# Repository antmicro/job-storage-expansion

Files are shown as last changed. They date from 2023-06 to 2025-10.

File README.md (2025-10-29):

# Jetson Orin Baseboard Storage Expansion Board

Copyright (c) 2023-2025 [Antmicro](https://www.antmicro.com)

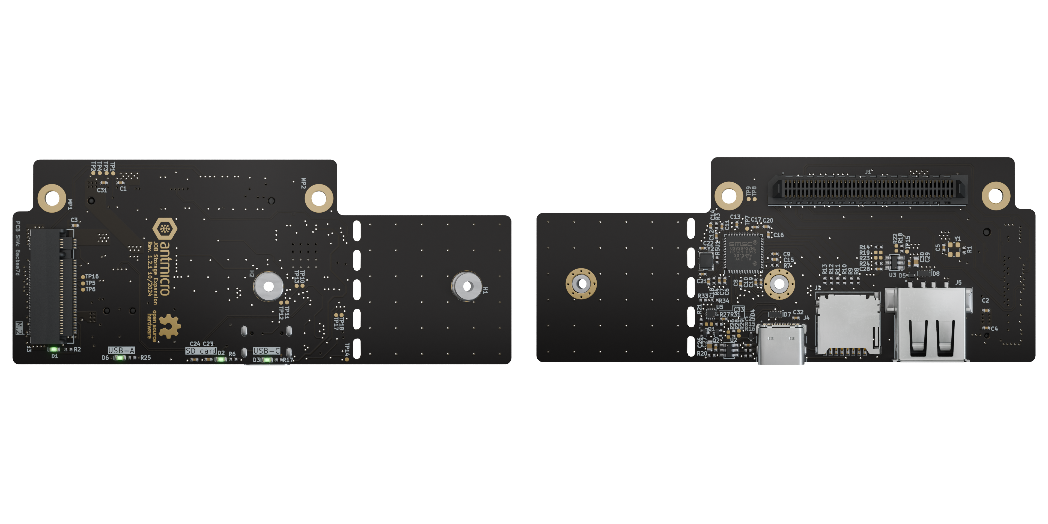
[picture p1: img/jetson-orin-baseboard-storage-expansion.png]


## Overview

This project contains open hardware design files for an expansion board compatible with Antmicro's [Jetson Orin Baseboard](https://github.com/antmicro/jetson-orin-baseboard).
The expansion board includes a MicroSD card slot and an M.2 (key-M) slot intended for connecting additional storage solutions to the Jetson Orin Baseboard.
It also includes an additional USB-C and USB type A connectors.
The M.2 slot supports 2280 and 2242 M.2 NVMe discs. 
The design files were prepared in KiCad 9.x.

## Key features

* Jetson Orin Baseboard expansion connector
* Support for 2280 and 2242 disc sizes
* M.2 key M
* MicroSD card reader with USB 2.0 interface
* USB-C and USB type A

## Project structure 

The main directory contains KiCad PCB project files, LICENSE, and README.
The remaining files are stored in the following directories: 
 
* `img` - contains graphics for this README

## Licensing

This project is published under the [Apache-2.0](LICENSE) license.

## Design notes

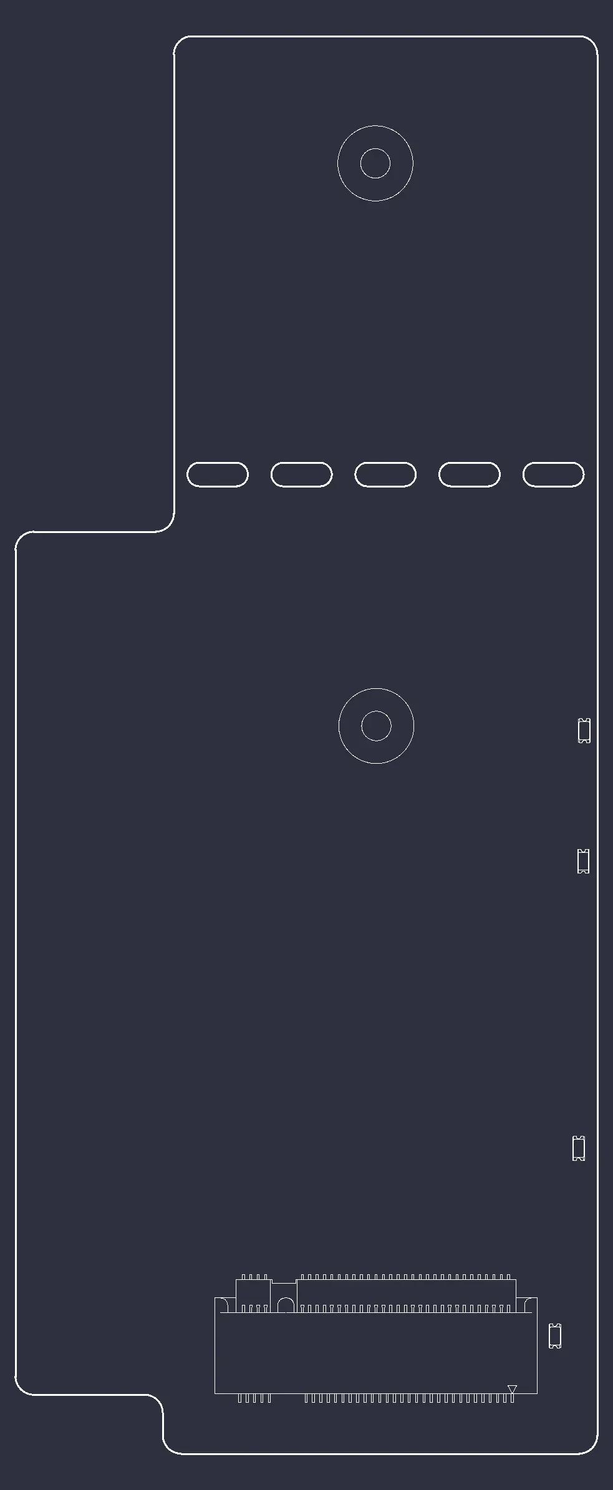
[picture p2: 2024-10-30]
assets/wireframe/wireframe_descriptions_top.webp

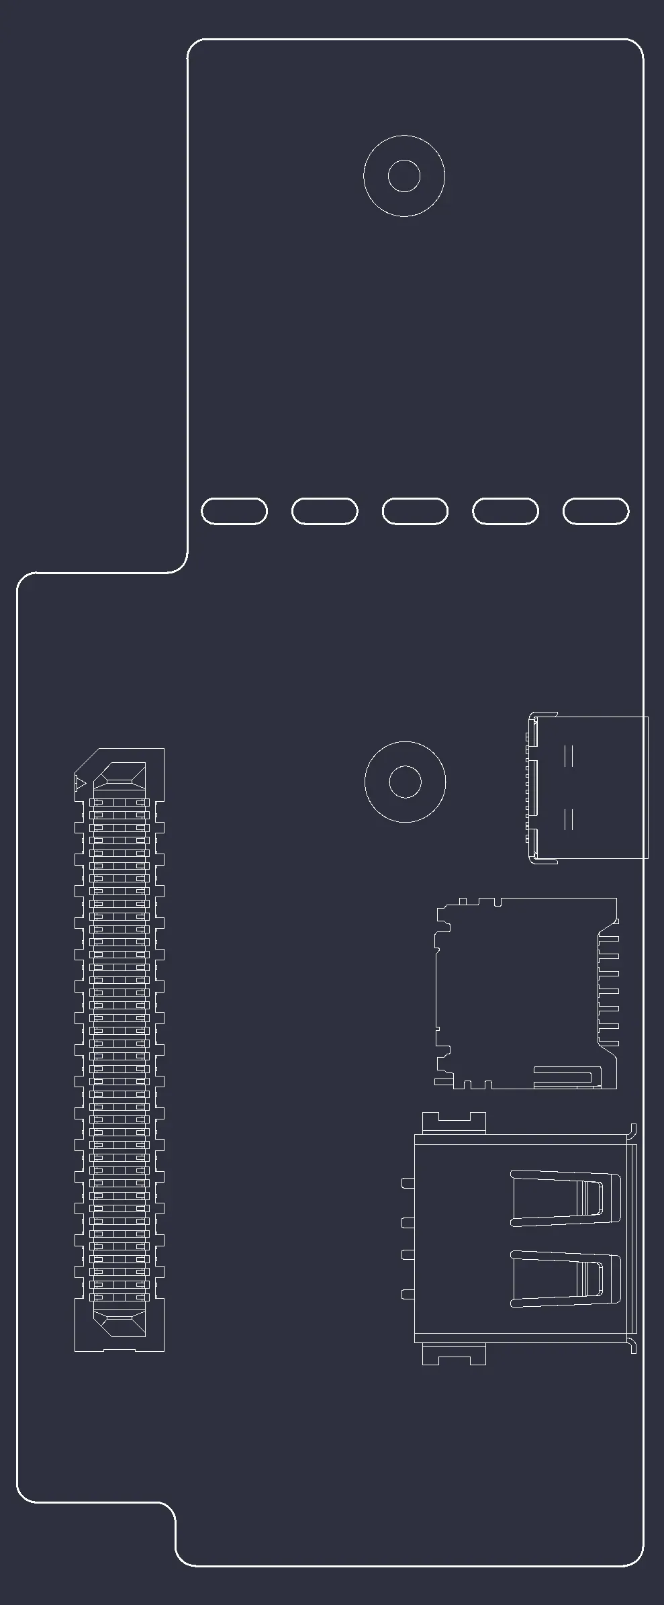
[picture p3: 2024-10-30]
assets/wireframe/wireframe_dimensions_bottom.webp

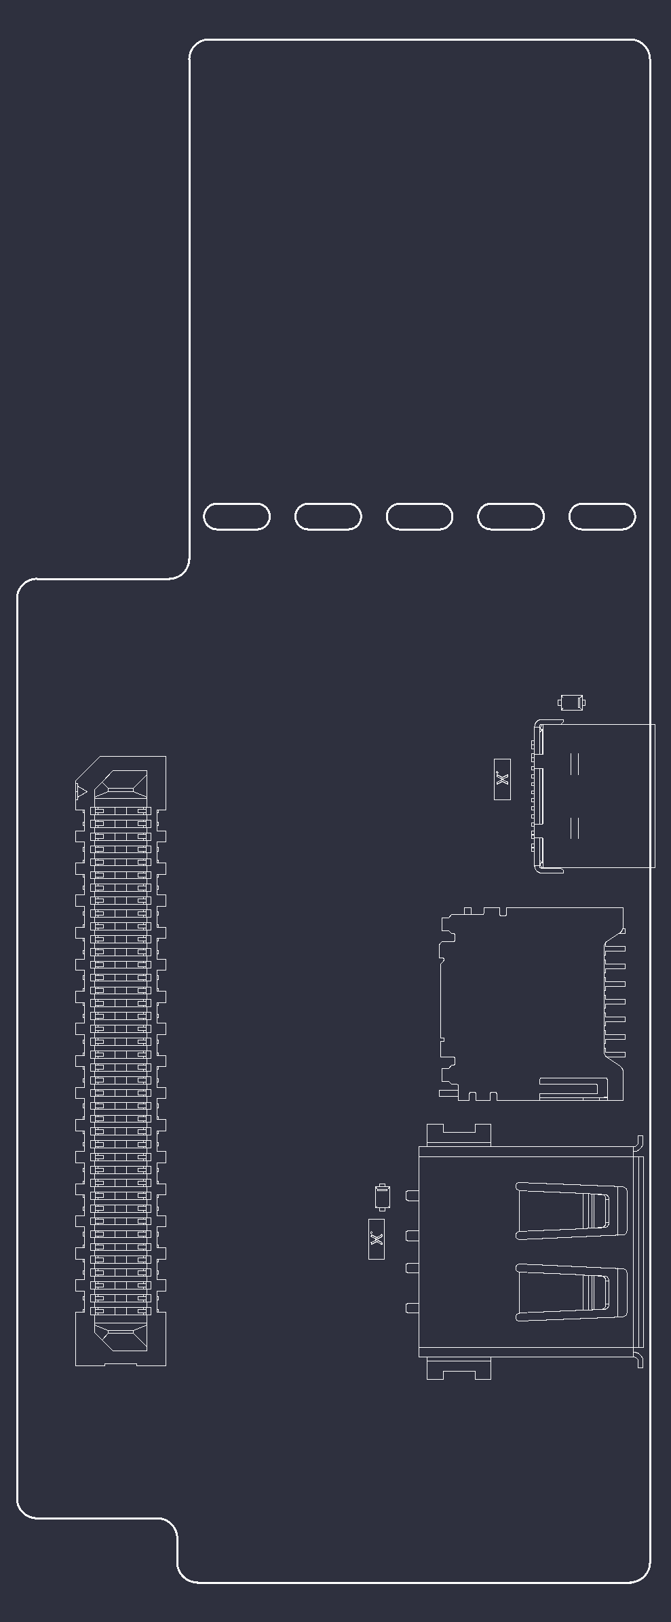
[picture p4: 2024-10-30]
assets/wireframe/wireframe_descriptions_bottom.png

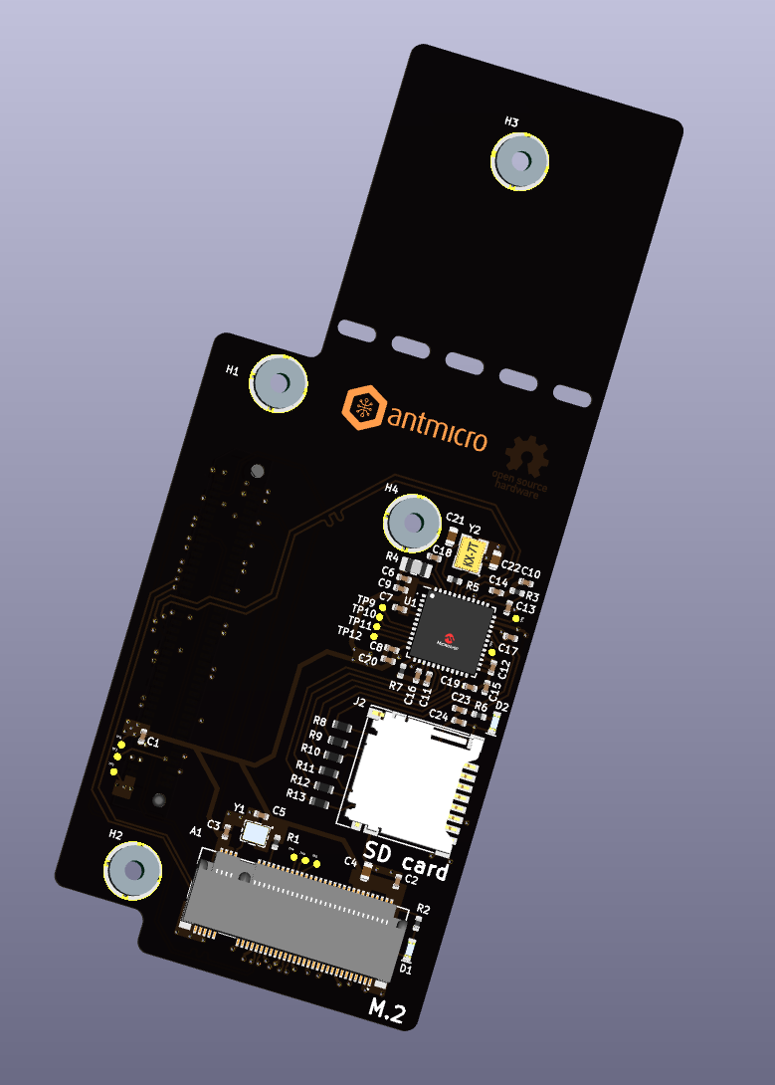
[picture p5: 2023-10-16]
img/storage-expansion-board.png

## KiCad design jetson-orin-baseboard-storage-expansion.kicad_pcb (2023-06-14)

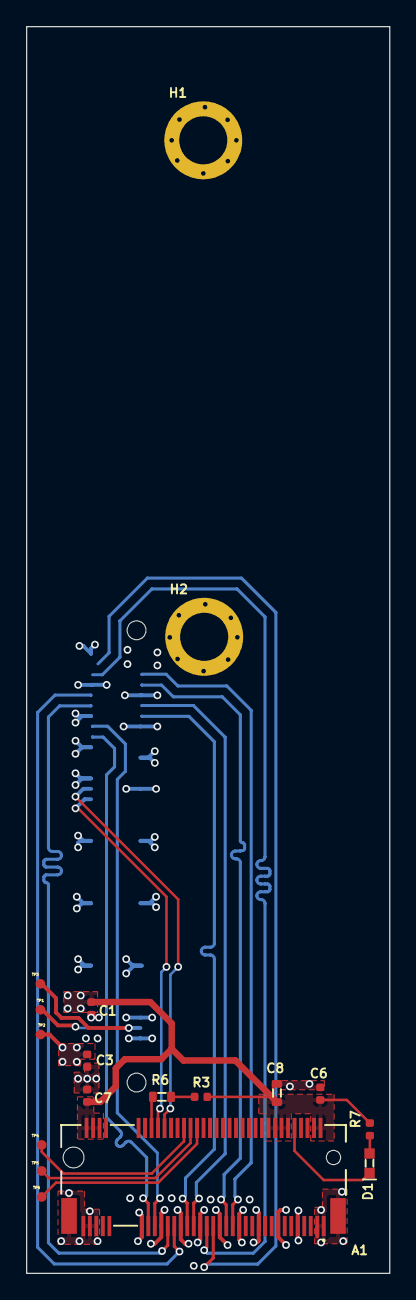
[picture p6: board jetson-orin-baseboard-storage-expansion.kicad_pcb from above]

Board: 4 copper layers, 27.9 x 95.9 mm, 19 parts (1 on the bottom side), 25 nets.

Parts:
A1: Bus_M.2_1-2199230-6; Bus_M.2_Socket_Key_M_TE_1-2199230-6
C1, C3: C_1u_0402; C_0402_1005Metric
C6, C7: C_10u_0402; C_0402_1005Metric
C8: C_100n_0603; C_0603_1608Metric
D1: LED_G_0603_KP-1608ZGC; LED_0603_1608Metric_G
H1, H2: Spacer_H2.5mm_9774025151; Spacer_SMD_M2.5_H2.5mm_Wurth_9774025151
J1: J_ERM8-040-XX.X-X-DV-XX_SAMTEC; ERM8-040-05.0_SAMTEC
R3: R_4k7_0402; R_0402_1005Metric
R6: R_0R_0603; R_0603_1608Metric
R7: R_200R_0402; R_0402_1005Metric
TP1, TP2, TP3, TP4, TP5, TP6: TP_0.75mm_SMD; TP_SMD_0.75mm

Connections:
3V3_STDB: J1.74, TP3.1
+1V8: J1.73, TP1.1
+3V3: A1.2 (3V3), A1.4 (3V3), A1.12 (3V3), A1.14 (3V3), A1.16 (3V3), A1.18 (3V3), A1.70 (3V3), A1.72 (3V3), A1.74 (3V3), C1.2, C6.2, C7.2, C8.2, J1.67, J1.69, R3.2, R7.2
+5V: C3.2, J1.77, J1.79, TP2.1
+12V: J1.78, J1.80
/M.2/M2_M_SMB_CLK: A1.40 (SMB_CLK), TP6.1
/M.2/M2_M_SMB_DATA: A1.42 (SMB_DATA), TP5.1
/M.2/~M2_M_ALERT: A1.44 (ALERT), TP4.1
/M.2/~M2_M_PEWAKE0: A1.54 (~PEWAKE), R6.2
GND: A1.1 (GND), A1.3 (GND), A1.9 (GND), A1.15 (GND), A1.21 (GND), A1.27 (GND), A1.33 (GND), A1.39 (GND), A1.45 (GND), A1.51 (GND), A1.57 (GND), A1.71 (GND), A1.73 (GND), A1.75 (GND), A1.SH (SHIELD), C1.1, C3.1, C6.1, C7.1, C8.1, H1.1, H2.1, J1.01, J1.02, J1.04, J1.07, J1.10, J1.13, J1.16, J1.19, J1.22, J1.25, J1.28, J1.37, J1.38, J1.49, J1.50, J1.61, J1.62, J1.71, J1.72, J1.75, J1.76
unnamed: A1.10 (LED), D1.2
unnamed: D1.1, R7.1
unnamed: R3.1, R6.1
PCIE2_CLKREQ: A1.52 (~CLKREQ), J1.29
PCIE2_CLK_N: A1.53 (REFCLK_N), J1.15
PCIE2_CLK_P: A1.55 (REFCLK_P), J1.17
PCIE2_RST: A1.50 (~PERST), J1.27
PCIE2_RX0_N: A1.41 (PER0_N), J1.12
PCIE2_RX0_P: A1.43 (PER0_P), J1.14
PCIE2_RX1_N: A1.29 (PER1_N), J1.06
PCIE2_RX1_P: A1.31 (PER1_P), J1.08
PCIE2_TX0_N: A1.47 (PET0_N), J1.09
PCIE2_TX0_P: A1.49 (PET0_P), J1.11
PCIE2_TX1_N: A1.35 (PET1_N), J1.03
PCIE2_TX1_P: A1.37 (PET1_P), J1.05

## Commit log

2023-06-06 Create KiCad project
    [expansionConn.kicad_sch, jetson-orin-baseboard-storage-expansion.kicad_pcb, jetson-orin-baseboard-storage-expansion.kicad_sch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]
2023-06-07 Add layout for expansion connector and M.2 key M slot
    [expansionConn.kicad_sch, jetson-orin-baseboard-storage-expansion.kicad_pcb, jetson-orin-baseboard-storage-expansion.kicad_sch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]
2023-06-13 [#45539] Finish schematic + draw dif pairs and other signals
    [expansionConn.kicad_sch, jetson-orin-baseboard-storage-expansion.kicad_pcb, jetson-orin-baseboard-storage-expansion.kicad_sch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]
2023-06-14 [#45539] Add power traces and fix clerance DRC
    [jetson-orin-baseboard-storage-expansion.kicad_pcb]
2023-06-14 [#45539] Fix DRC & change via size to Eurocircuits standard
    [jetson-orin-baseboard-storage-expansion.kicad_pcb]
2023-06-14 [#45539] Change spacing of the m2 spacers, fix DRC, prepare labels for sd card reader
    [expansionConn.kicad_sch, jetson-orin-baseboard-storage-expansion.kicad_pcb, jetson-orin-baseboard-storage-expansion.kicad_sch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]
2023-10-16 [#45539] Apply changes after review
    [expansion-conn.kicad_sch, expansionConn.kicad_sch, jetson-orin-baseboard-storage-expansion.kicad_sch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]
2023-10-16 [#45990] Fix schematic flaws discussed in review
    [expansion-conn.kicad_sch, jetson-orin-baseboard-storage-expansion.kicad_sch, m-2.kicad_sch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]
2023-10-16 [#45990] Add logos to SD sheet
    [sd.kicad_sch]
2023-10-16 [#45990] Move expansion connector, add holes for screws
2023-10-16 [#45990] Route dif Pcie, place susclk gen
    [expansion-conn.kicad_sch, jetson-orin-baseboard-storage-expansion.kicad_sch, m-2.kicad_sch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]
2023-10-16 [#45990] Re-arrange elements on pcb
2023-10-16 [#45990] Trace SDIO and 3v3 lines
2023-10-16 [#45990] Fix silk screen drcs
    [expansion-conn.kicad_sch, jetson-orin-baseboard-storage-expansion.kicad_sch, m-2.kicad_sch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]
2023-10-16 [#45990] Route usb ic traces
2023-10-16 [#45990] Route dif USB
    [jetson-orin-baseboard-storage-expansion.kicad_sch, sd.kicad_sch]
2023-10-16 [#45990] Clean up power traces
2023-10-16 [#45990] Cosmetic changes for schematic, expand README
    [expansion-conn.kicad_sch, jetson-orin-baseboard-storage-expansion.kicad_sch, m-2.kicad_sch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]
2023-10-16 Minor traces fixes
2023-10-16 [#45990] Fix texts on PCB
    [expansion-conn.kicad_sch, jetson-orin-baseboard-storage-expansion.kicad_sch]
2023-10-16 [#45990] Switch VBUS_DET from VDDA to VDD33
    [sd.kicad_sch]
2023-10-16 [#45990] Move board name to copper, add Rev. num
2023-10-16 Resize board name
2023-10-16 Add DNP for susclk
    [m-2.kicad_sch]
2023-10-16 [#45990] Remove non-sourceable elements from BOMS
    [expansion-conn.kicad_sch, m-2.kicad_sch, sd.kicad_sch]
2023-10-16 Alter geometry of PCIe traces to fit EC
2023-10-16 Add proper PCB SHA string
2023-10-16 Fix MPN and Value on ERM8
    [expansion-conn.kicad_sch, jetson-orin-baseboard-storage-expansion.kicad_sch]
2023-10-16 [#47315] Fix bug with SD card detect pin
    [sd.kicad_sch]
2023-10-16 Bump revision to 1.1.0
    [expansion-conn.kicad_sch, jetson-orin-baseboard-storage-expansion.kicad_sch, m-2.kicad_sch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]
2023-10-16 Fix DRC
    [expansion-conn.kicad_sch, jetson-orin-baseboard-storage-expansion.kicad_sch, m-2.kicad_sch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]
2023-10-16 Clean up schematic layout
    [expansion-conn.kicad_sch, jetson-orin-baseboard-storage-expansion.kicad_sch, m-2.kicad_sch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]
2023-10-16 Fix misaligned M.2 connector
    [jetson-orin-baseboard-storage-expansion.kicad_sch, m-2.kicad_sch]
2023-10-16 [#49775] Update with standarized OSHW logo
    [jetson-orin-baseboard-storage-expansion.kicad_sch]
2023-10-16 [#49775] Cleanup net lists
    [expansion-conn.kicad_sch, m-2.kicad_sch, sd.kicad_sch]
2023-10-16 [#49775] Update mounting holes with standarized components
    [expansion-conn.kicad_sch, jetson-orin-baseboard-storage-expansion.kicad_sch]
2023-10-16 [#49775] Update power flags
    [jetson-orin-baseboard-storage-expansion.kicad_sch, m-2.kicad_sch]
2023-10-16 Bump revision date, update PCB SHA string
    [expansion-conn.kicad_sch, jetson-orin-baseboard-storage-expansion.kicad_sch, m-2.kicad_sch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]
2023-10-18 Add OHP assets
    [stackup.csv]
2024-01-16 Standardise samtech connector
    [expansion-conn.kicad_sch]
2024-05-23 [#56948] Update symbol/footprint links; Migrate to KiCad 7
    [#56948] Update from lib; clean DRC
    Remove Public False property from components
    [expansion-conn.kicad_sch, jetson-orin-baseboard-storage-expansion.kicad_sch, m-2.kicad_sch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]
2024-08-19 [#64006] Updated footprints
2024-08-19 [#64006] Addresed all changes suggested in PCB review
    [m-2.kicad_sch, sd.kicad_sch]
2024-08-19 [#64006] Added "Not in schematic" flag to logos
2024-08-19 Revision bump to 1.1.2
    [expansion-conn.kicad_sch, jetson-orin-baseboard-storage-expansion.kicad_sch, m-2.kicad_sch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]
2024-08-19 [#64333] Added USB-A and USB-C to the schematics
    [sd.kicad_sch]
2024-09-11 [#64333] Continued routing components
    [expansion-conn.kicad_sch, jetson-orin-baseboard-storage-expansion.kicad_sch, m-2.kicad_sch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]
2024-09-11 [#64333] Added kibuzzard labels to all the ports and added PCB SHA label
2024-09-11 [#64333] Revision bump to 1.2.0
    [expansion-conn.kicad_sch, jetson-orin-baseboard-storage-expansion.kicad_sch, m-2.kicad_sch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]
2024-09-11 [#64333] Added handling for USB-C CC lines and ESD protection according to review
    [sd.kicad_sch]
2024-09-11 [#64333] Changed USB-C CC controller to FUSB303B
    [sd.kicad_sch]
2024-09-11 [#64333] Fixed schematic after review
    [sd.kicad_sch]
2024-09-11 [#64333] Rerouted components after schematics change
2024-09-11 [#64333] Fixing DRC problems and issues pinted in PCB review
2024-09-11 [#64333] Fixed all DRC problems and made plane for 3V3 and 5V
2024-09-11 [#64333] Tuned all high speed lines lenghs and added thermal reliefs to components that are on 3V3 and 5V planes
2024-09-11 [#64333] Added usb to net class and added via stitching
    [sd.kicad_sch]
2024-09-11 Updated symbols from lib. Minor DRC and ERC fixes
    [expansion-conn.kicad_sch, m-2.kicad_sch, sd.kicad_sch]
2024-10-15 [#67311] Replace symbol and footprint of U1, Bump revision
    [expansion-conn.kicad_sch, jetson-orin-baseboard-storage-expansion.kicad_sch, m-2.kicad_sch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]
2024-10-15 [#67311] Fix ERC errors
    [sd.kicad_sch]
2024-10-15 [#67311] Update USB footprint
2025-10-29 [#83351] Project refresh 81589
    [expansion-conn.kicad_sch, jetson-orin-baseboard-storage-expansion.kicad_sch, m-2.kicad_sch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]

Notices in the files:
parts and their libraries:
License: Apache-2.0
